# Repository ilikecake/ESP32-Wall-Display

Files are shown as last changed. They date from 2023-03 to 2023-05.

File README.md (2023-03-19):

# ESP32 Wall Display

This project is a small wall display that shows temperature, humidity and barometric pressure from a remote sensor. The display and sensor communicate over MQTT using [Home Assistant](https://www.home-assistant.io/) as a backend. The display is housed in a 3D printed case and takes 5V DC power. This display is designed to work with my [weather station](https://github.com/ilikecake/ESP32-Weather-Station), but can be easily adapter to other sensors if desired.

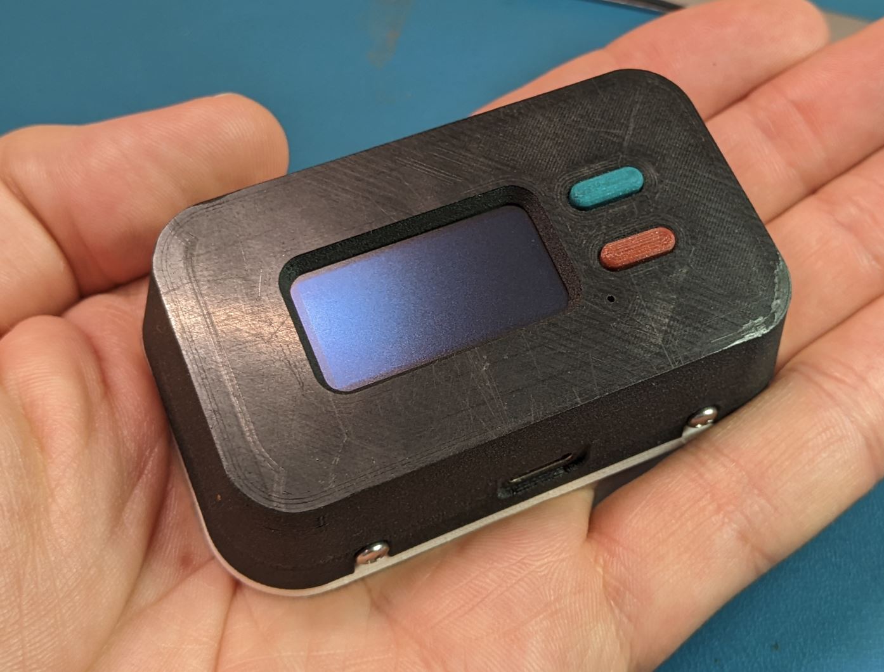
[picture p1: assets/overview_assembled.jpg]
[](https://raw.githubusercontent.com/ilikecake/ESP32-Wall-Display/main/assets/overview_assembled.jpg)

Features
* Small OLED display (~1.3" diagonal)
* Two buttons to toggle through displays. Can be adapted to other functions if desired.
* RGB LED can be set by Home Assistant over MQTT to notify the user.
* Measures local temperature, humidity, barometric pressure using a BME280 sensor.
* 3D printed case.
* Powered by 5V (standard USB power supplies will work)
* Wifi connectivity from ESP32.

Building this project will require:
* 3D printer to print the case components.
* Basic soldering capability for the wiring.

For information on how to build this project, see the wiki.

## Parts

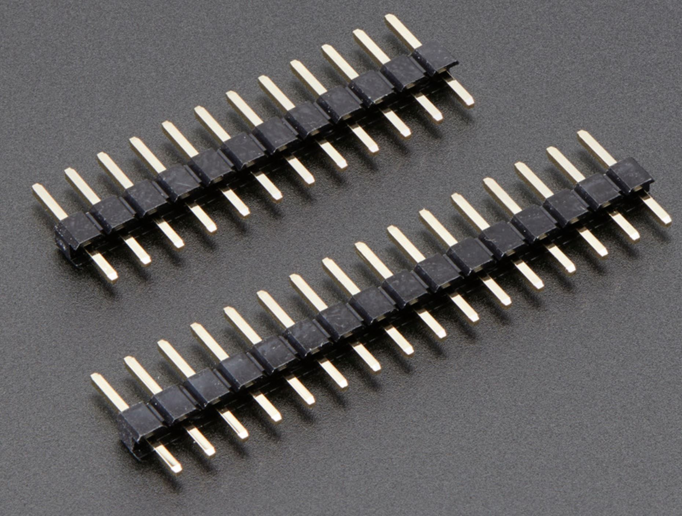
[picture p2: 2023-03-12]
assets/BOM_Feather_Male_Headers.jpg

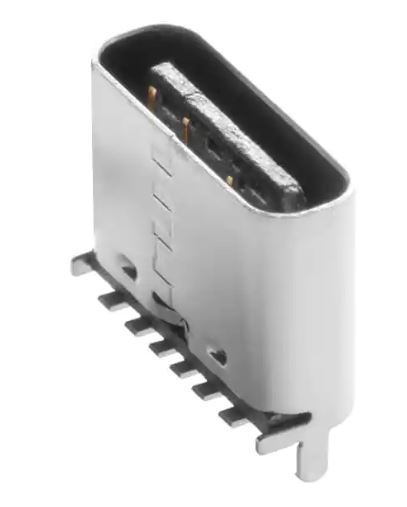
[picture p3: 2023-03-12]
assets/BOM_USB_TYPE_C_Plug.jpg

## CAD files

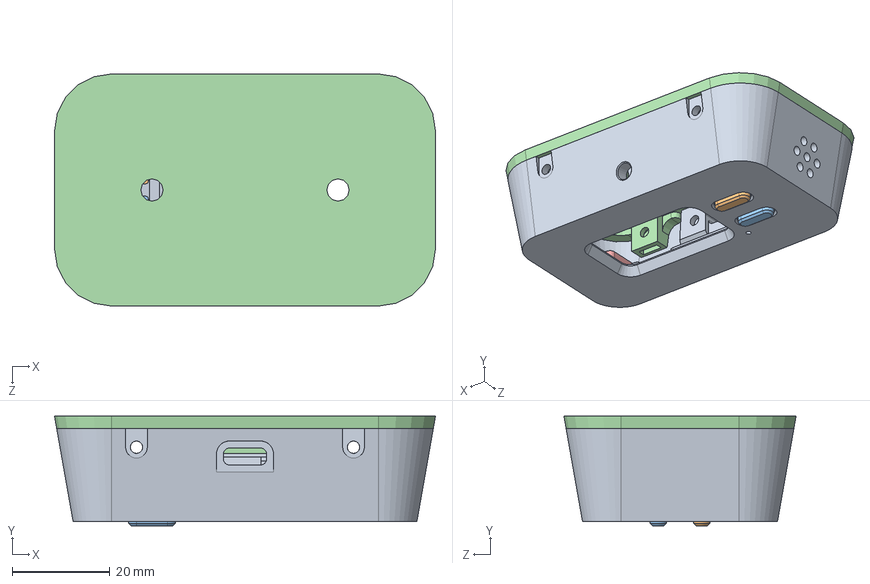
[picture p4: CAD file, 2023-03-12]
printed parts/source/ESP32 Wall Display.SLDASM
78.0 x 22.4 x 47.5 mm
Front - ESP32 Wall Display
Button 1 - ESP32 Wall Display
Button 2 - ESP32 Wall Display
Back - ESP32 Wall Display
Display Holder 1 - ESP32 Wall Display
Display Holder 2 - ESP32 Wall Display x 2

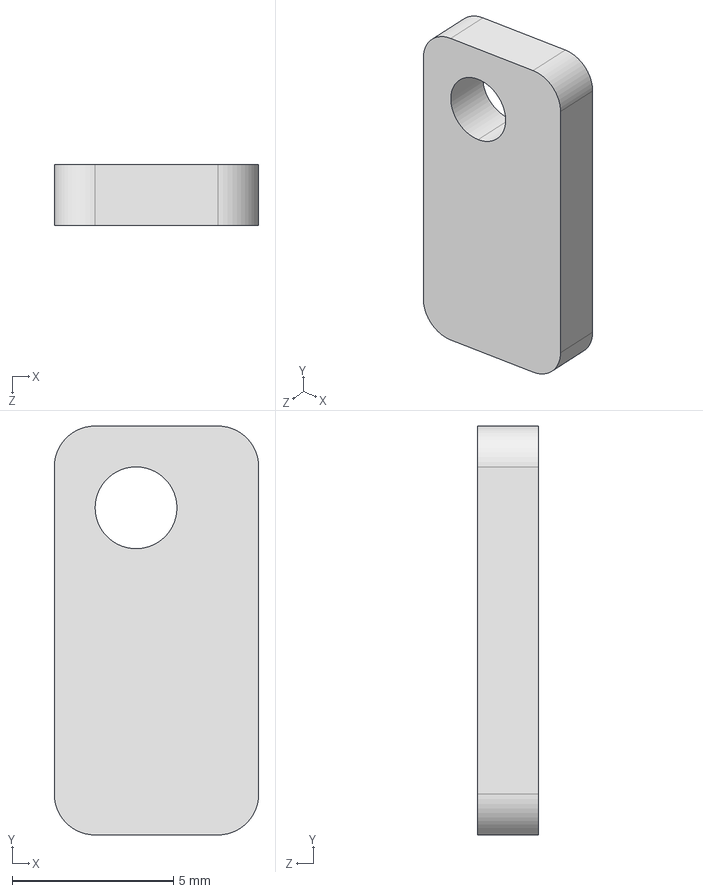
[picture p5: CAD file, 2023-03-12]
printed parts/source/Display Holder 2 - ESP32 Wall Display.STEP
6.35 x 12.7 x 1.90 mm

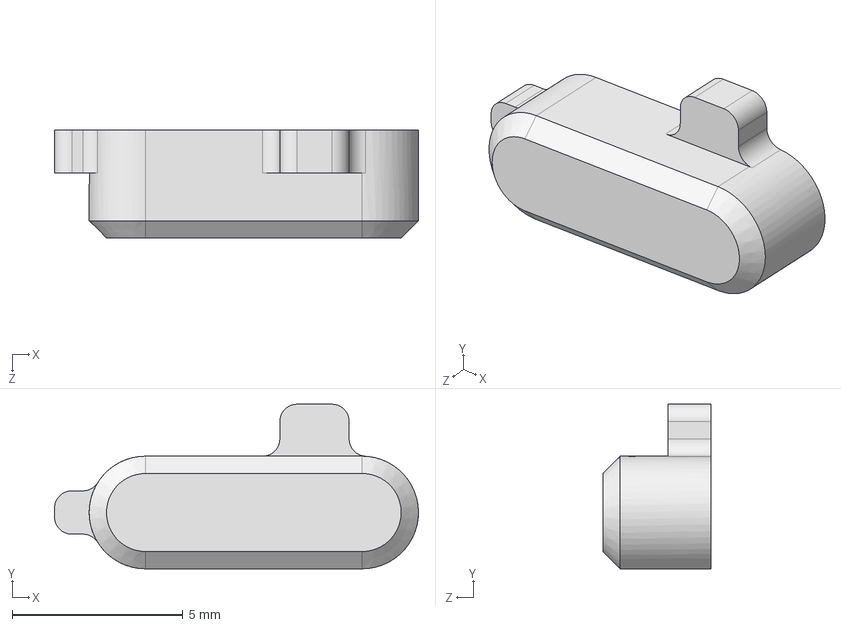
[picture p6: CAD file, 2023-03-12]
printed parts/source/Button 2 - ESP32 Wall Display.STEP
10.7 x 4.83 x 3.17 mm

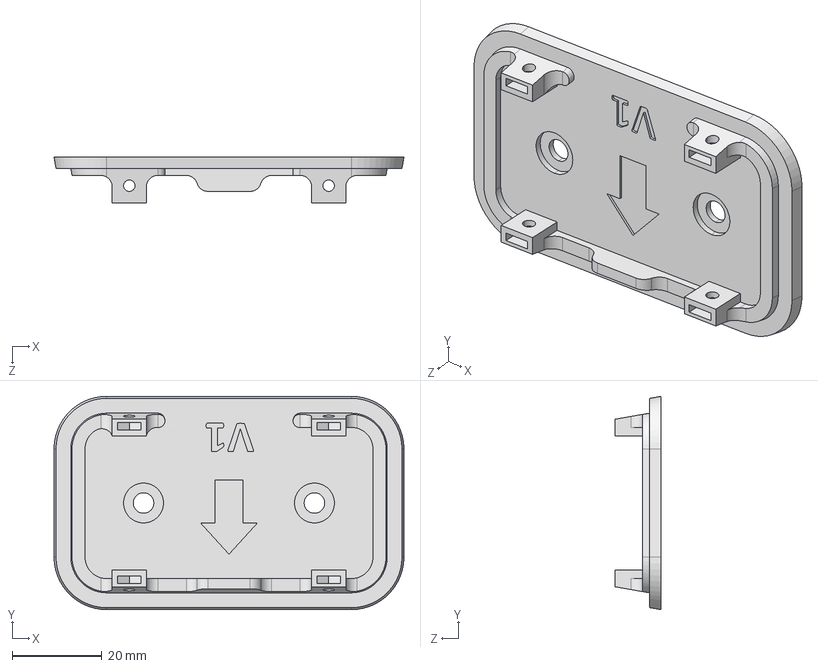
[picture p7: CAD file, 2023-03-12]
printed parts/source/Back - ESP32 Wall Display.STEP
78.0 x 47.5 x 10.2 mm

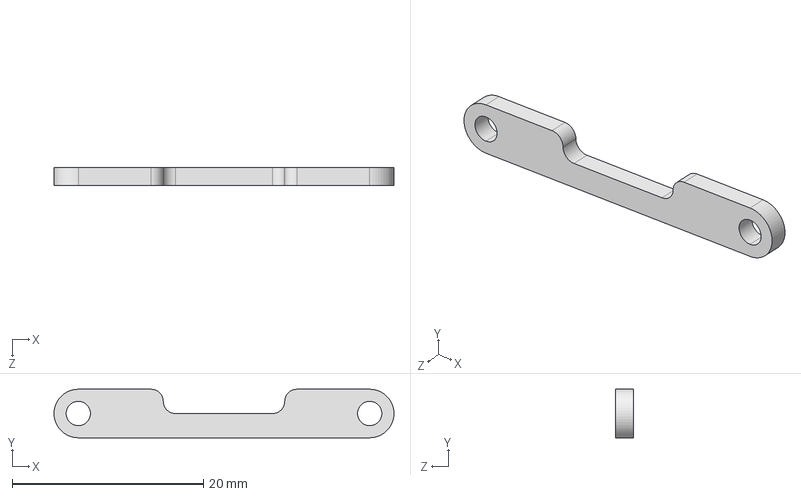
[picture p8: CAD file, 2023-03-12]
printed parts/source/Display Holder 1 - ESP32 Wall Display.STEP
35.6 x 5.08 x 1.90 mm

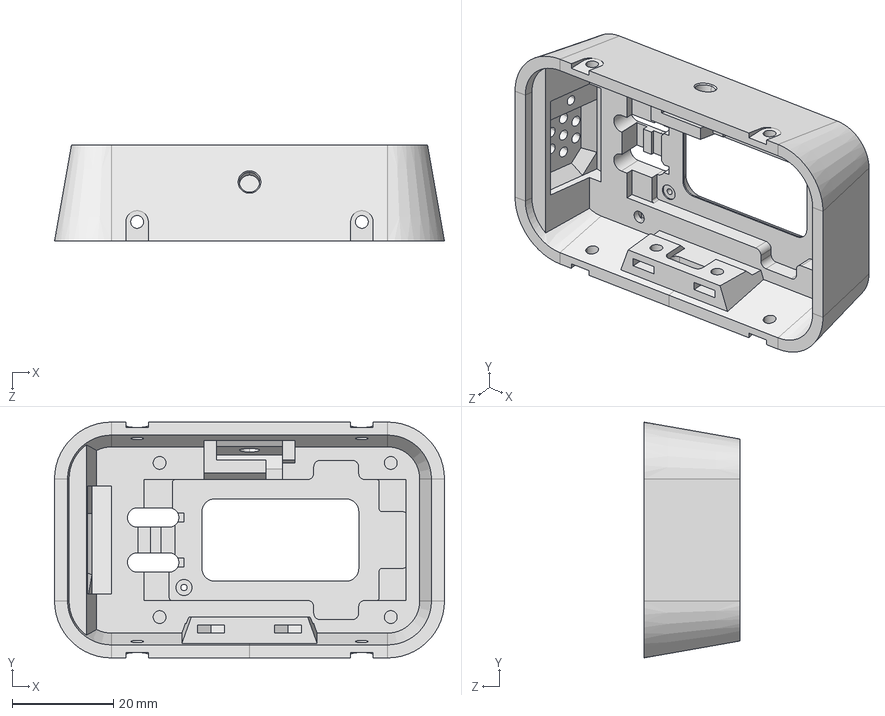
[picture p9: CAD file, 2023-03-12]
printed parts/source/Front - ESP32 Wall Display.STEP
77.1 x 46.6 x 19.1 mm

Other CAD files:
printed parts/source/Button 1 - ESP32 Wall Display.STEP
printed parts/Back - ESP32 Wall Display.STL
printed parts/Button 1 - ESP32 Wall Display.STL
printed parts/Button 2 - ESP32 Wall Display.STL
printed parts/Display Holder 1 - ESP32 Wall Display.STL
printed parts/Display Holder 2 - ESP32 Wall Display.STL
printed parts/Front - ESP32 Wall Display.STL
printed parts/source/Back - ESP32 Wall Display.SLDPRT
printed parts/source/Button 1 - ESP32 Wall Display.SLDPRT
printed parts/source/Button 2 - ESP32 Wall Display.SLDPRT
printed parts/source/Display Holder 1 - ESP32 Wall Display.SLDPRT
printed parts/source/Display Holder 2 - ESP32 Wall Display.SLDPRT
printed parts/source/Front - ESP32 Wall Display.SLDPRT

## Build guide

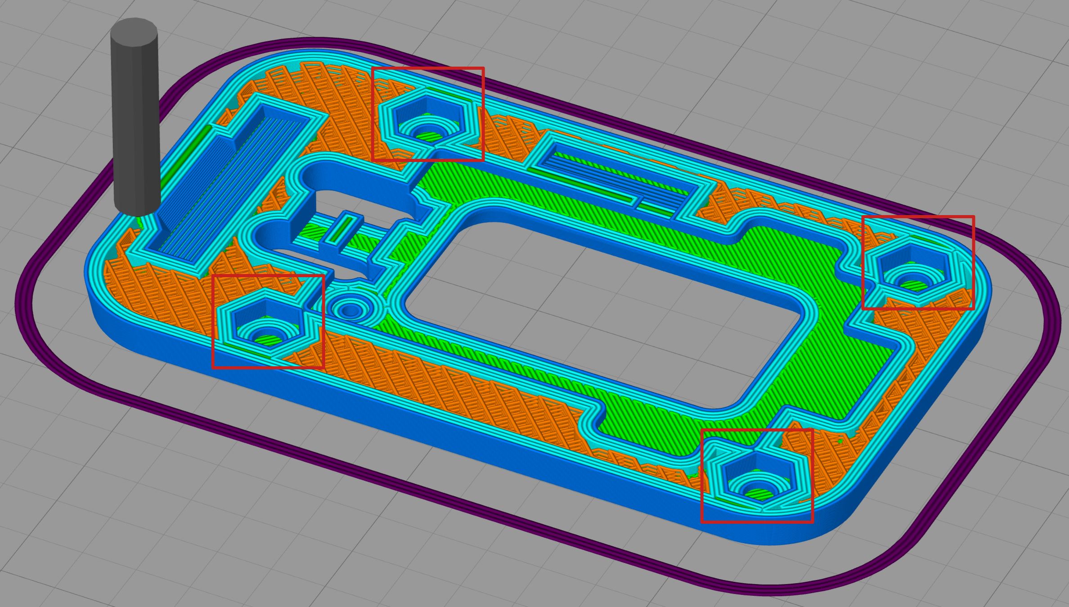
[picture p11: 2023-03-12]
assets/printing_embedded_nuts.JPG

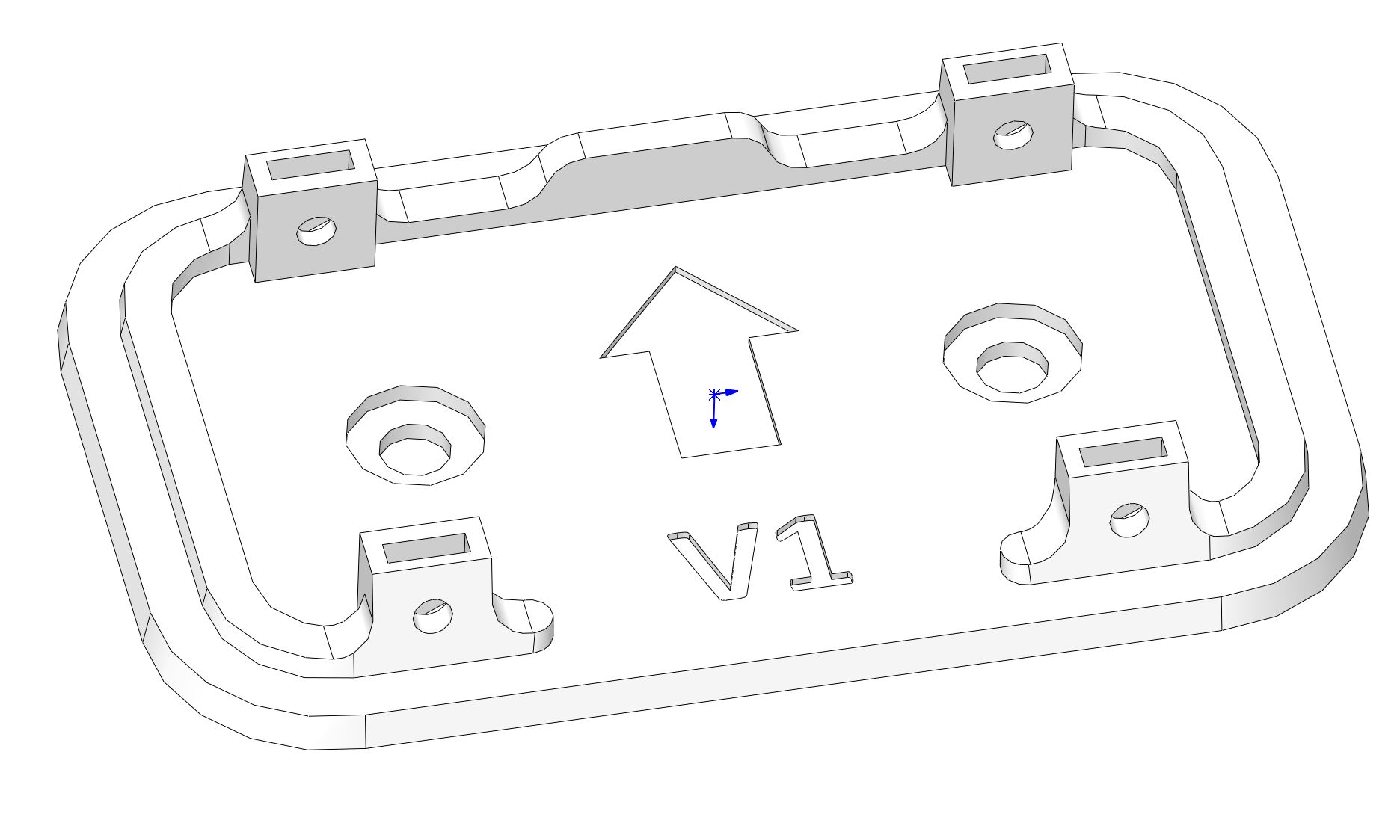
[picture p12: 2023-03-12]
assets/printing_case_back.JPG

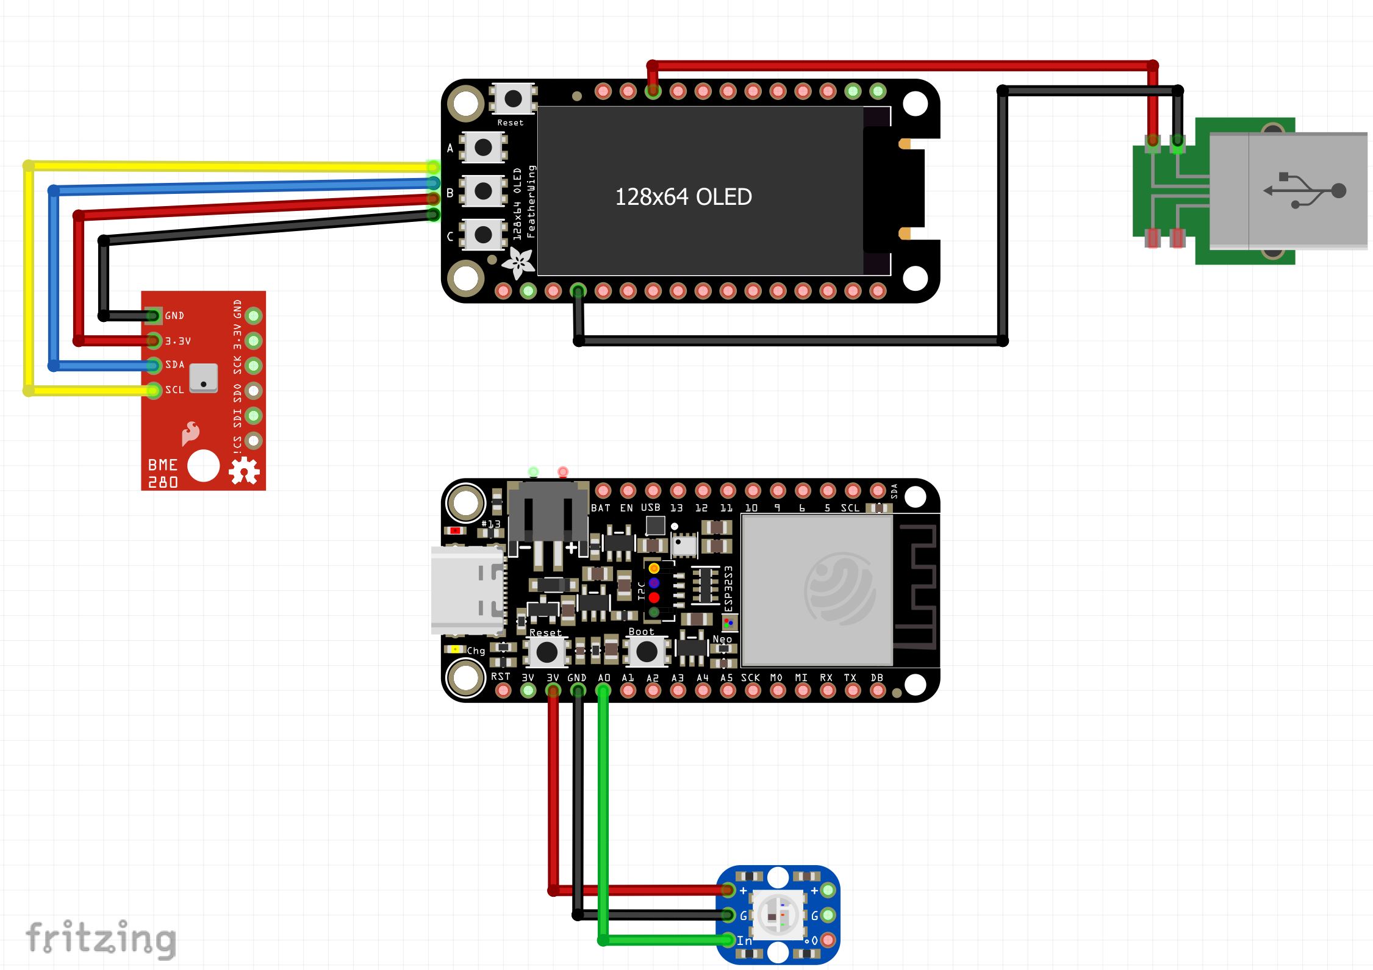
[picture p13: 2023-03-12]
assets/wiring_schematic.JPG

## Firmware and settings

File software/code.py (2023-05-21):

import json
import time
import board
import digitalio
import rtc
import displayio
import weather_display
import adafruit_ntp
import countio
import microcontroller

import ipaddress
import ssl
import wifi
import socketpool
import adafruit_requests
import neopixel

from adafruit_bme280 import basic as adafruit_bme280
import adafruit_minimqtt.adafruit_minimqtt as MQTT

#Clear any old display data
displayio.release_displays()

TIMEOUT_COUNTS = 200    #How many times to try connecting to Wifi and MQTT before reset.
RETRY_DELAY = 30        #How long to wait between retries of wifi and MQTT connection. Note that the connect functions also have delay built in, so real delay will be longer than this.
NTP_Time_Set = False    #Set to True when a valid time was recieved from NTP

#Global pixel data. The pixel is used during initialization to indicate the status.
#   - Red:      Connecting to wifi
#   - Blue:     Connectingn to MQTT broker
#   - White:    Getting time from NTP
#   - Yellow:   Network error in main loop, reconnecting.
#Once the device is initialized, the pixel is controlled by the MQTT broker.
PixelRGBValue = [0, 0, 0]
PixelBrightness = 0
PixelOn = False
PixelUpdate = False     #Set to true to indicate that the pixel needs to be updated. Pixel is updated in the main loop.

PixelState = {"state":          "OFF",                      \
              "brightness":     0,                          \
              "color":          {"r": 0, "g": 0, "b": 0}}

NewRemoteData = False   #Set to true to indicate that new remote data is available. This is set in the MQTT callbacks, and handled in the main loop.
DST_is_applied = -1

#A counter that is used to control when the device checks for the time from NTP. By default the device checks
#every ~15 min for NTP if it does not have a valid time, and every 24 hours if it has previously gotten a good time.
NTP_Retry = 0

try:
    from secrets import secrets
except ImportError:
    print("WiFi secrets are kept in secrets.py, please add them there!")
    raise   #TODO: What does this do?

pixel = neopixel.NeoPixel(board.A0, 1)
wifi.radio.hostname = secrets["device_ID"]

#Set up button interrupts
button_A = countio.Counter(board.D9, edge=countio.Edge.FALL, pull=digitalio.Pull.UP)
button_C = countio.Counter(board.D5, edge=countio.Edge.FALL, pull=digitalio.Pull.UP)

#Initialize variables
LocalData = {
    "temperature":  0,
    "humidity":     0,
    "pressure":     0
}

RemoteData = {
    "temperature":  0,
    "humidity":     0,
    "pressure":     0
}

MQTT_Light_topic = secrets["device_status_topic"] + '#'
MQTT_Remote_Data_Topic = secrets["Remote_Data_Topic"]

MQTT_Config_light = "homeassistant/light/" + secrets["UUID"]+"/config"
MQTT_Light_State_Topic = "homeassistant/light/" + secrets["UUID"] + "/state"
MQTT_Light_Command_Topic = "homeassistant/light/" + secrets["UUID"] + "/command"

MQTT_State_Topic = "homeassistant/sensor/" + secrets["UUID"] + "/state"
MQTT_Config_Temp = "homeassistant/sensor/" + secrets["UUID"]+"_temp/config"
MQTT_Config_Humidity = "homeassistant/sensor/"+secrets["UUID"]+"_humidity/config"
MQTT_Config_Pressure = "homeassistant/sensor/"+secrets["UUID"]+"_pressure/config"

MQTT_Config_Upper_Button = "homeassistant/device_automation/" + secrets["UUID"]+"/upper_button/config"
MQTT_State_Upper_Button = "homeassistant/device_automation/" + secrets["UUID"]+"/upper_button/state"
MQTT_Config_Lower_Button = "homeassistant/device_automation/" + secrets["UUID"]+"/lower_button/config"
MQTT_State_Lower_Button = "homeassistant/device_automation/" + secrets["UUID"]+"/lower_button/state"


MQTT_lwt = "homeassistant/sensor/"+secrets["UUID"]+"_" + secrets["device_ID"] + "/lwt"

MQTT_Device_info = {"ids":               [secrets["UUID"]],                                         \
                    "name":              secrets["device_name"],                                    \
                    "suggested_area":    "Kitchen",                                                 \
                    "manufacturer":      "Pat Satyshur",                                            \
                    "model":             "Home Assistant Discovery for "+secrets["device_name"],    \
                    "sw_version":        "https://github.com/ilikecake/ESP32-Wall-Display",         \
                    "configuration_url": "https://github.com/ilikecake/ESP32-Wall-Display"          }

MQTT_Config_Temp_Payload = json.dumps({"device_class":           "temperature",                             \
                                       "name":                   secrets["device_name"] + " Temperature",   \
                                       "state_topic":            MQTT_State_Topic,                          \
                                       "unit_of_measurement":    "°F",                                      \
                                       "value_template":         "{{value_json.temperature}}",              \
                                       "unique_id":              secrets["UUID"]+"_temp",                   \
                                       "availability_topic":     MQTT_lwt,                                  \
                                       "payload_available":      "online",                                  \
                                       "payload_not_available":  "offline",                                 \
                                       "device":                 MQTT_Device_info                           })

MQTT_Config_Humidity_Payload = json.dumps({"device_class":           "humidity",                                \
                                           "name":                   secrets["device_name"] + " Humidity",      \
                                           "state_topic":            MQTT_State_Topic,                          \
                                           "unit_of_measurement":    "%",                                       \
                                           "value_template":         "{{value_json.humidity}}",                 \
                                           "unique_id":              secrets["UUID"]+"_humidity",               \
                                           "availability_topic":     MQTT_lwt,                                  \
                                           "payload_available":      "online",                                  \
                                           "payload_not_available":  "offline",                                 \
                                           "device":                 MQTT_Device_info                           })

MQTT_Config_Pressure_Payload = json.dumps({"device_class":           "pressure",                                \
                                           "name":                   secrets["device_name"] + " Pressure",      \
                                           "state_topic":            MQTT_State_Topic,                          \
                                           "unit_of_measurement":    "hPa",                                     \
                                           "value_template":         "{{value_json.pressure}}",                 \
                                           "unique_id":              secrets["UUID"]+"_pressure",               \
                                           "availability_topic":     MQTT_lwt,                                  \
                                           "payload_available":      "online",                                  \
                                           "payload_not_available":  "offline",                                 \
                                           "device":                 MQTT_Device_info                           })

MQTT_Config_Light_Payload = json.dumps({"name":                         secrets["device_name"] + " Light",      \
                                        "schema":                       'json',                                 \
                                        "state_topic":                  MQTT_Light_State_Topic,                 \
                                        "command_topic":                MQTT_Light_Command_Topic,               \
                                        "brightness":                   'true',                                 \
                                        "color_mode":                   'true',                                 \
                                        "supported_color_modes":        ["rgb"],                                \
                                        "unique_id":                    secrets["UUID"]+"_light",               \
                                        "availability_topic":           MQTT_lwt,                               \
                                        "payload_available":            "online",                               \
                                        "payload_not_available":        "offline",                              \
                                        "device":                       MQTT_Device_info                        })

MQTT_Config_Upper_Button_Payload = json.dumps({"automation_type":        "trigger",                  \
                                            "type":                   "button_short_press",       \
                                          "subtype":                "Upper Button",             \
                                          "topic":                  MQTT_State_Upper_Button,         \
                                          "payload":                "Click",                    \
                                          "device":                 MQTT_Device_info            })

MQTT_Config_Lower_Button_Payload = json.dumps({"automation_type":        "trigger",                  \
                                          "type":                   "button_short_press",       \
                                          "subtype":                "Lower Button",             \
                                          "topic":                  MQTT_State_Lower_Button,         \
                                          "payload":                "Click",                    \
                                          "device":                 MQTT_Device_info            })

#MQTT Callbacks. Most of these are not used.
def connect(mqtt_client, userdata, flags, rc):
    #This function will be called when the mqtt_client is connected successfully to the broker.
    #print("Connected to MQTT Broker!")
    #print("Flags: {0}\n RC: {1}".format(flags, rc))
    pass

def disconnect(mqtt_client, userdata, rc):
    #This method is called when the mqtt_client disconnects from the broker.
    #print("Disconnected from MQTT Broker!")
    pass

def subscribe(mqtt_client, userdata, topic, granted_qos):
    #This method is called when the mqtt_client subscribes to a new feed.
    #print("Subscribed to {0} with QOS level {1}".format(topic, granted_qos))
    pass

def unsubscribe(mqtt_client, userdata, topic, pid):
    #This method is called when the mqtt_client unsubscribes from a feed.
    #print("Unsubscribed from {0} with PID {1}".format(topic, pid))
    pass

def publish(mqtt_client, userdata, topic, pid):
    #This method is called when the mqtt_client publishes data to a feed.
    #print("Published to {0} with PID {1}".format(topic, pid))
    pass

def message(client, topic, message):
    global RemoteData
    global NewRemoteData
    global PixelRGBValue
    global PixelOn
    global PixelBrightness
    global PixelUpdate
    global PixelState
    #print("New message on topic {0}: {1}".format(topic, message))

    if (topic == MQTT_lwt) and (message == "offline"):
        #If the device resets quickly, it appears that the LWT message is not reset when the device reconnects.
        #This leads to the LWT message firing even through the device is online.
        #The device will never intentionally send a LWT message of 'offline', so if that message is recieved,
        #resend the 'online' message.
        mqtt_client.publish(MQTT_lwt, 'online', qos=1, retain=True)

    if topic == MQTT_Light_Command_Topic:
        PixelUpdate = True
        print("in: ", message)
        light_command = json.loads(message)
        PixelState["state"] = light_command["state"]
        if "color" in light_command:
            PixelState["color"] = light_command["color"]
        if "brightness" in light_command:
            PixelState["brightness"] = light_command["brightness"]
    # Method called when a client's subscribed feed has a new value.
    if topic == MQTT_Remote_Data_Topic:
        #There is new remote data from the server.
        RemoteData = json.loads(message)
        NewRemoteData = True
    elif secrets["device_status_topic"] in topic:
        #This is where we listen for updates to the pixel state from the MQTT server.
        if 'rgb/set' in topic:
            #Set new pixel RGB value
            PixelRGBValue = [int(x) for x in message.split(",")]
            PixelUpdate = True
        elif 'light/switch' in topic:
            #Turn the pixel on or off
            if message == 'ON':
                PixelOn = True
                PixelUpdate = True
            elif message == 'OFF':
                PixelOn = False
                PixelUpdate = True
        elif 'brightness/set' in topic:
            #Set brightness. Brightness should be 0-1
            PixelBrightness = int(message)/256
            PixelUpdate = True

pool = socketpool.SocketPool(wifi.radio)

# Set up a MiniMQTT Client
mqtt_client = MQTT.MQTT(broker=secrets["mqtt_broker_ip"],
                        port=int(secrets["mqtt_broker_port"]),
                        username=secrets["mqtt_broker_user"],
                        password=secrets["mqtt_broker_pass"],
                        socket_pool=pool,
                        ssl_context=ssl.create_default_context(),
                        )

#Connect callback handlers to mqtt_client
mqtt_client.on_connect = connect
mqtt_client.on_disconnect = disconnect
mqtt_client.on_subscribe = subscribe
mqtt_client.on_unsubscribe = unsubscribe
mqtt_client.on_publish = publish
mqtt_client.on_message = message
mqtt_client.will_set(MQTT_lwt,'offline')

def ConnectToNetwork():
    global pixel
    global mqtt_client
    global TheDisplay
    Retries = 0

    TheDisplay.ShowStatus()

    while Retries < TIMEOUT_COUNTS:
        Retries = Retries + 1
        TheDisplay.ClearStatusText()

        if wifi.radio.ipv4_address is None:
            #Not connected to wifi
            print("Connecting to SSID: {0:s}...".format(secrets["ssid"]), end =".")
            TheDisplay.StatusText(1,'Connecting to Wifi')
            TheDisplay.StatusText(2,"SSID: %s" % secrets["ssid"])
            pixel.fill((50, 0, 0))  #Red

            try:
                wifi.radio.connect(secrets["ssid"], secrets["password"])
            except Exception as e:  # pylint: disable=broad-except
                print("Failed ({0:d}/{1:d}). Error: ".format(Retries, TIMEOUT_COUNTS), e)
                TheDisplay.StatusText(3,"Failed ({0:d}/{1:d})".format(Retries, TIMEOUT_COUNTS))
                TheDisplay.StatusText(4,e)
                time.sleep(RETRY_DELAY)
            else:
                if wifi.radio.ipv4_address is not None:
                    print("ok")
                    print("  IP: ", wifi.radio.ipv4_address)
                    Retries = Retries - 1   #Wifi is connected, but MQTT won't try to connect until the next time through the loop.
        else:
            #Connected to wifi, try to connect to MQTT
            print("Connecting to MQTT broker at %s..." % mqtt_client.broker, end =".")
            TheDisplay.StatusText(1,"Connecting to MQTT")
            TheDisplay.StatusText(2,"At: %s" % secrets["mqtt_broker_ip"])
            pixel.fill((0, 0, 50))  #Blue

            try:
                mqtt_client.connect()       #This command has a built in retry/timeout, so it takes about 3 min to fail.
                mqtt_client.subscribe(MQTT_Light_topic, qos=1)
                mqtt_client.subscribe(MQTT_Remote_Data_Topic, qos=1)
                mqtt_client.subscribe(MQTT_Light_Command_Topic, qos=1)

                mqtt_client.publish(MQTT_lwt, 'online', qos=1, retain=True)
                mqtt_client.publish(MQTT_Config_Temp, MQTT_Config_Temp_Payload, qos=1, retain=True)
                mqtt_client.publish(MQTT_Config_Humidity, MQTT_Config_Humidity_Payload, qos=1, retain=True)
                mqtt_client.publish(MQTT_Config_Pressure, MQTT_Config_Pressure_Payload, qos=1, retain=True)
                mqtt_client.publish(MQTT_Config_light, MQTT_Config_Light_Payload, qos=1, retain=True)
                mqtt_client.publish(MQTT_Config_Upper_Button, MQTT_Config_Upper_Button_Payload, qos=1, retain=True)
                mqtt_client.publish(MQTT_Config_Lower_Button, MQTT_Config_Lower_Button_Payload, qos=1, retain=True)

            except Exception as e:  # pylint: disable=broad-except
                print("Failed ({0:d}/{1:d}). Error:".format(Retries, TIMEOUT_COUNTS), e)
                TheDisplay.StatusText(3,"Failed ({0:d}/{1:d})".format(Retries, TIMEOUT_COUNTS))
                TheDisplay.StatusText(4,e)
                time.sleep(RETRY_DELAY)     #Note: there is a delay/retry built into the connect function also, so this will take longer than you think.
            else:
                #We are connected to wifi and the MQTT broker.
                pixel.fill((0, 0, 0))  #Off
                print("ok")
                return
    #If we get here, the timeout count is reached. Hard reset the device.
    microcontroller.reset()

#This function has a shorter timeout delay and timeout count than the wifi and MQTT connect functions
# This is because NTP is not required for the device to function, and I don't want the device to stop working if external internet access is lost.
# If this function times out, the device will keep working and periodically check again for NTP access.
# This function will take 5-10 sec to timeout if the NTP servier is not accessable.
# Calling this function with SilentMode = true will not change the display or the pixel. For periodic updates to the time during normal operation, use this mode.
def GetTimeFromNTP(SilentMode = False):
    global pixel
    global DST_is_applied
    NTP_Retries = 5
    NTP_Retry_Delay = 1     #sec
    Retries = 0

    if secrets["NTP_ip"] is '':
        print("Skipping time setup")
        return False

    if SilentMode == False:
        TheDisplay.ClearStatusText()
        TheDisplay.StatusText(1,"Setting time...")
        TheDisplay.ShowStatus()
        pixel.fill((50, 50, 50))  #White

    print("Setting time...", end =".")

    while True:
        if Retries > NTP_Retries:
            #if we get here, NTP time sync failed
            print("skipped")
            return False
        else:
            Retries = Retries + 1

        try:
            TZ_OFFSET = int(secrets["timezone"]) # time zone offset in hours from UTC
            ntp = adafruit_ntp.NTP(pool, server=secrets["NTP_ip"], tz_offset=TZ_OFFSET)
            DST_is_applied = -1
            HandleDST(ntp.datetime)

        except Exception as e:  # pylint: disable=broad-except
            print("Failed to get time from NTP. Error ({0:d}/{1:d}):".format(Retries, NTP_Retries), e)
            if SilentMode == False:
                TheDisplay.StatusText(2,"Failed ({0:d}/{1:d})".format(Retries, NTP_Retries))
                TheDisplay.StatusText(3,e)
            time.sleep(NTP_Retry_Delay)
        else:
            if SilentMode == False:
                pixel.fill((0, 0, 0))  #Off
            print("ok")
            return True

def GetLocalData():
    #TODO: I2C Error checking goes here...
    #TODO: Type conversion goes here?
    global LocalData

    temp_C = bme280.temperature

    LocalData["temperature"] = (temp_C * 9/5) + 32 #F
    LocalData["humidity"] = bme280.humidity
    LocalData["pressure"] = bme280.pressure

def RemoveMQTT():
    #Sends empty config packets to home assistant. This tells home assistant to delete these sensors from its config.
    #Should never be called, but I am saving this here in case it is needed for debug.
    print("Delete the MQTT sensor")
    mqtt_client.publish(MQTT_Config_Temp, '', qos=1, retain=True)
    mqtt_client.publish(MQTT_Config_Humidity, '', qos=1, retain=True)
    mqtt_client.publish(MQTT_Config_Pressure, '', qos=1, retain=True)
    mqtt_client.publish(MQTT_Config_light, '', qos=1, retain=True)
    mqtt_client.publish(MQTT_Config_Upper_Button, '', qos=1, retain=True)
    mqtt_client.publish(MQTT_Config_Lower_Button, '', qos=1, retain=True)
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

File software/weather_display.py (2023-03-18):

import displayio
import terminalio
from adafruit_display_text import label
import adafruit_displayio_sh1107

DisplayState_Status = 1
DisplayState_Remote = 2
DisplayState_Local = 3
DisplayState_Blank = 4

class WeatherDisplay:
    def __init__(self, i2c):
        self._display_bus = displayio.I2CDisplay(i2c, device_address=0x3C)
        self._DisplayWidth = 128
        self._DisplayHeight = 64
        self._BorderWidth = 2
        self._display = adafruit_displayio_sh1107.SH1107(self._display_bus, width=self._DisplayWidth, height=self._DisplayHeight, rotation=180, brightness=1)

        self._oldMin = -1
        self._oldDay = -1
        
        #These counters are decremented everytime the update function is called.
        self._DataCounter = 0               #Counts down from DataCounterMax to zero. When it reaches zero, connection with the remote sensor is assumed lost.
        self._DisplayTimeoutCounter = 0     #Counts down to zero. Display state is updated when it reaches zero. Initial value can be different for different display states as seen below.
        
        self._DataCounterMax = 500           #Top value for the data counter
        self._RemoteDisplayTimout = 250      #Top value for the display counter when showing the remote sensor data
        self._LocalDisplayTimout = 250       #Top value for the display counter when showing the local sensor data
        self._StatusDisplayTimout = 250      #Top value for the display counter when showing status messages. This value can be overridden by the ShowStatus function.
        
        #Set initial state of the display and data
        self._DisplayState = DisplayState_Status
        self._DisplayStateChanged = False
        self._RemoteDataLost = True

        self._LocalData = {"temperature":  0,
                           "humidity":     0,
                           "pressure":     0 }
                           
        self._RemoteData = {"temperature":  0,
                            "humidity":     0,
                            "pressure":     0 }

        # Make the display groups
        fullscreen_bitmap = displayio.Bitmap(self._DisplayWidth, self._DisplayHeight, 1)
        inner_bitmap = displayio.Bitmap(self._DisplayWidth - self._BorderWidth * 2, self._DisplayHeight - self._BorderWidth * 2, 1)
        color_palette_black = displayio.Palette(1)
        color_palette_black[0] = 0x000000
        color_palette_white = displayio.Palette(1)
        color_palette_white[0] = 0xFFFFFF

        #Blank group
        self._BlankDisplay = displayio.Group()
        blank_sprite = displayio.TileGrid(fullscreen_bitmap, pixel_shader=color_palette_black, x=0, y=0)
        self._BlankDisplay.append(blank_sprite)

        #Message Group
        self._MessageDisplay = displayio.Group()
        #Draw border
        border_sprite_init = displayio.TileGrid(fullscreen_bitmap, pixel_shader=color_palette_white, x=0, y=0)
        inner_sprite_init = displayio.TileGrid(inner_bitmap, pixel_shader=color_palette_black, x=self._BorderWidth, y=self._BorderWidth)
        self._MessageDisplay.append(border_sprite_init)
        self._MessageDisplay.append(inner_sprite_init)
        #Make four lines of text.
        self._MessageText = [label.Label(terminalio.FONT, text=" "*20, color=0xFFFFFF),
                             label.Label(terminalio.FONT, text=" "*20, color=0xFFFFFF),
                             label.Label(terminalio.FONT, text=" "*20, color=0xFFFFFF),
                             label.Label(terminalio.FONT, text=" "*20, color=0xFFFFFF),
                             label.Label(terminalio.FONT, text=" "*20, color=0xFFFFFF)]

        #self._MessageText1 = label.Label(terminalio.FONT, text=" "*20, color=0xFFFFFF)
        self._MessageText[0].anchor_point = (0, 0)
        self._MessageText[0].anchored_position = (self._BorderWidth*2, 1)
        self._MessageDisplay.append(self._MessageText[0])
        #Line 2
        #self._MessageText2 = label.Label(terminalio.FONT, text=" "*20, color=0xFFFFFF)
        self._MessageText[1].anchor_point = (0, 0)
        self._MessageText[1].anchored_position = (self._BorderWidth*2, 11)
        self._MessageDisplay.append(self._MessageText[1])
        #Line 3
        #self._MessageText3 = label.Label(terminalio.FONT, text=" "*20, color=0xFFFFFF)
        self._MessageText[2].anchor_point = (0, 0)
        self._MessageText[2].anchored_position = (self._BorderWidth*2, 22)
        self._MessageDisplay.append(self._MessageText[2])
        #Line 4
        #self._MessageText[3] = label.Label(terminalio.FONT, text=" "*20, color=0xFFFFFF)
        self._MessageText[3].anchor_point = (0, 0)
        self._MessageText[3].anchored_position = (self._BorderWidth*2, 33)
        self._MessageDisplay.append(self._MessageText[3])
        #Line 5
        self._MessageText[4].anchor_point = (0, 0)
        self._MessageText[4].anchored_position = (self._BorderWidth*2, 44)
        self._MessageDisplay.append(self._MessageText[4])

        #Group to display the weather
        self._WeatherDisplay = displayio.Group()
        border_sprite_weather = displayio.TileGrid(fullscreen_bitmap, pixel_shader=color_palette_white, x=0, y=0)
        inner_sprite_weather = displayio.TileGrid(inner_bitmap, pixel_shader=color_palette_black, x=self._BorderWidth, y=self._BorderWidth)
        self._WeatherDisplay.append(border_sprite_weather)
        self._WeatherDisplay.append(inner_sprite_weather)

        line_bitmap = displayio.Bitmap(self._DisplayWidth, 2, 1)
        line_tile = displayio.TileGrid(line_bitmap, pixel_shader=color_palette_white, x=0, y=50)
        self._WeatherDisplay.append(line_tile)

        self._WeatherLabel = label.Label(terminalio.FONT, text=" "*10, color=0xFFFFFF)
        self._WeatherLabel.anchor_point = (0, 0)
        self._WeatherLabel.anchored_position = (self._BorderWidth*2, 1)
        self._WeatherDisplay.append(self._WeatherLabel)

        self._TempValue = label.Label(terminalio.FONT, text=" "*5, scale=2, color=0xFFFFFF)
        self._TempValue.anchor_point = (1.0, 0)
        self._TempValue.anchored_position = (75, 10)
        self._WeatherDisplay.append(self._TempValue)

        temp_unit_text = label.Label(terminalio.FONT, text="F", color=0xFFFFFF)
        temp_unit_text.anchor_point = (0, 0)
        temp_unit_text.anchored_position = (77, 12)
        self._WeatherDisplay.append(temp_unit_text)

        self._HumidityValue = label.Label(terminalio.FONT, text=" "*5, color=0xFFFFFF)
        self._HumidityValue.anchor_point = (1, 0)
        self._HumidityValue.anchored_position = (45, 35)
        self._WeatherDisplay.append(self._HumidityValue)

        self._PressureValue = label.Label(terminalio.FONT, text=" "*9, color=0xFFFFFF)
        self._PressureValue.anchor_point = (1, 0)
        self._PressureValue.anchored_position = (110, 35)
        self._WeatherDisplay.append(self._PressureValue)
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

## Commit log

2023-02-23 Add device setup to MQTT discovery packets
2023-03-11 Remove debug lines, fix display rotation
    [code.py, weather_display.py]
2023-03-12 Initial commit of SW solid models
    [Back - ESP32 Wall Display.SLDPRT, Button 1 - ESP32 Wall Display.SLDPRT, Button 2 - ESP32 Wall Display.SLDPRT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]
2023-03-12 Update export coordinates
    [Front - ESP32 Wall Display.SLDPRT]
2023-03-12 Initial commit of front STL file
    [Front - ESP32 Wall Display.STL]
2023-03-12 Fixed export coordinates
    [Front - ESP32 Wall Display.STL]
2023-03-12 Update export coordinates (again)
    [Front - ESP32 Wall Display.SLDPRT]
2023-03-12 Create Back - ESP32 Wall Display.STL
    [Back - ESP32 Wall Display.STL]
2023-03-12 Updated export coordinates
    [Back - ESP32 Wall Display.SLDPRT]
2023-03-12 Added export coordinates
    [Button 1 - ESP32 Wall Display.SLDPRT]
2023-03-12 Create Button 1 - ESP32 Wall Display.STL
    [Button 1 - ESP32 Wall Display.STL]
2023-03-12 Create Button 2 - ESP32 Wall Display.STL
    [Button 2 - ESP32 Wall Display.STL]
2023-03-12 Create Display Holder 1 - ESP32 Wall Display.STL
    [Display Holder 1 - ESP32 Wall Display.STL]
2023-03-12 Create Display Holder 2 - ESP32 Wall Display.STL
    [Display Holder 2 - ESP32 Wall Display.STL]
2023-03-12 Initial commit of STEP files
    [Back - ESP32 Wall Display.STEP, Button 1 - ESP32 Wall Display.STEP, Button 2 - ESP32 Wall Display.STEP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]
2023-03-12 Update ESP32 Wall Display.SLDASM
    [ESP32 Wall Display.SLDASM]
2023-03-12 Upload wiring pictures
2023-03-18 Fix to make the device blank after DisplayShouldBeOn returns false
    [weather_display.py]
2023-03-19 Send button presses over MQTT
    Implemented MQTT Device Triggers for the button presses.
2023-03-21 Make pixel discoverable over MQTT
    This does not work quite right yet. The broker does not receive the response from the device properly.
    [code.py]
2023-05-21 Fix to keep the LWT from firing when the device is on
    [code.py]
